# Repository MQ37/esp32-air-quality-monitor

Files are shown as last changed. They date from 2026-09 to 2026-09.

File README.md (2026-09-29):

# ESP32 air-quality monitor




An ESP32 air-quality monitor for my desk: firmware, a 3D-printable enclosure and wiring for BME680, CCS811 and ENS160 sensors.

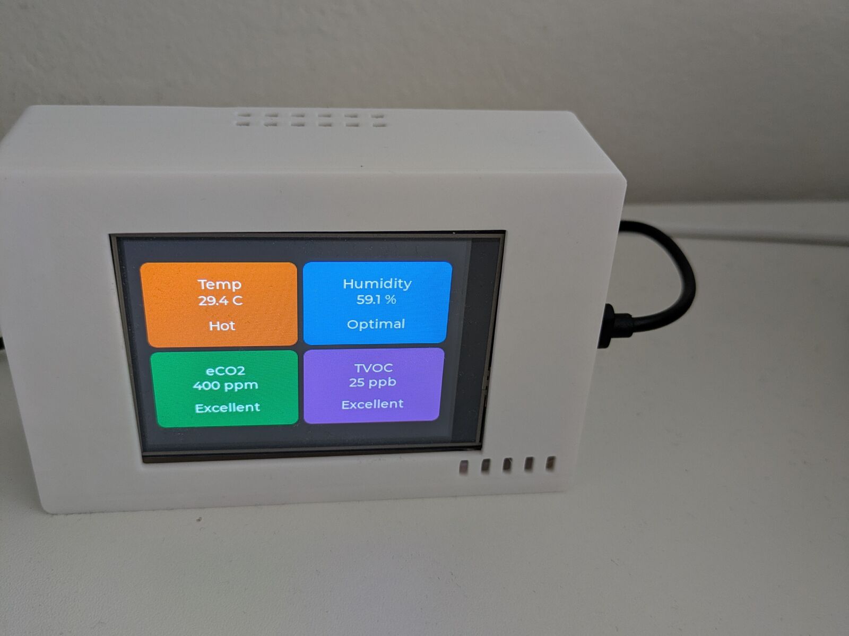
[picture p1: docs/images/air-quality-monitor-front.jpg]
The finished monitor: a white printed case with a screen showing temperature, humidity, eCO2 and TVOC


It shows temperature, humidity, eCO2 and TVOC on the board's built-in 3.2" screen, and this repo has everything I used to build it.

I'm a software person, and the hardware side was the hard part for me. If you're in the same spot, this README spells out the things I had to figure out.

**Blog post:** [ESP32 - building an air-quality monitor with a coding agent](https://kopecky.io/blog/2026-09-28-esp32-air-quality-monitor/)

> **Status: the cleaned-up firmware in this repo is untested on hardware.** I built this monitor and ran an earlier, messier version of the firmware on it. Then I tidied the code for this repo (LVGL from the component manager, shared I2C helper, one pins header, BME680 gas heater off, a fix to the eCO2/TVOC averaging). It compiles cleanly with ESP-IDF v5.5.2, but I'm traveling and can't flash the board right now, so this exact version hasn't run on it yet. If something breaks, please open an issue.

---

- [What it measures](#what-it-measures)
- [Bill of materials](#bill-of-materials)
- [How it's wired](#how-its-wired)
- [The enclosure](#the-enclosure)
- [Build and flash the firmware](#build-and-flash-the-firmware)
- [Troubleshooting](#troubleshooting)
- [How the firmware works](#how-the-firmware-works)
- [Repo layout](#repo-layout)
- [Notes and lessons learned](#notes-and-lessons-learned)
- [Acknowledgements and licenses](#acknowledgements-and-licenses)

## What it measures

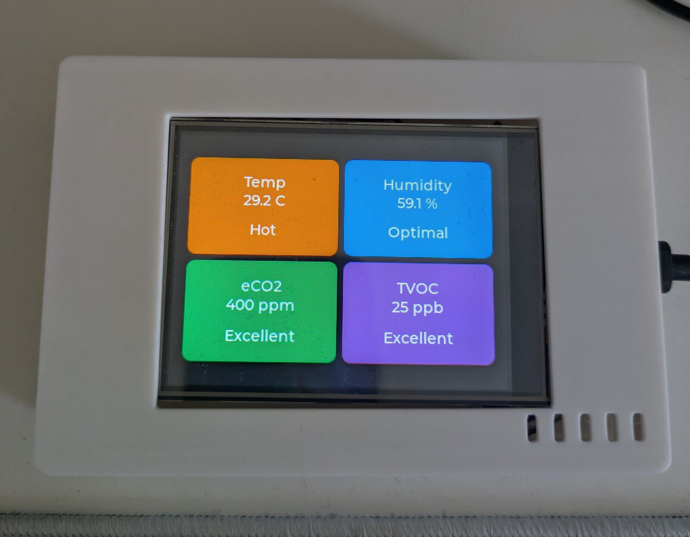
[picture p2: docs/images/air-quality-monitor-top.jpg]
Close-up of the screen with its four cards


| Card | Sensor | Label under the value, from low to high |
| --- | --- | --- |
| **Temp** (°C) | BME680 | Cold (< 18) · Cool (18–20) · Comfortable (20–26) · Warm (26–28) · Hot (≥ 28) |
| **Humidity** (% RH) | BME680 | Dry (< 30) · Low (30–40) · Optimal (40–60) · High (60–70) · Humid (≥ 70) |
| **eCO2** (ppm) | CCS811 | Excellent (< 600) · Good (600–800) · Fair (800–1000) · Poor (1000–1500) · Very Poor (≥ 1500) |
| **TVOC** (ppb) | ENS160 | Excellent (< 100) · Good (100–200) · Fair (200–400) · Poor (400–600) · Very Poor (≥ 600) |

**Four values, three sensor modules.** The BME680 module gives temperature and humidity, the CCS811 module gives eCO2 and the ENS160 module gives TVOC. The ENS160 board is a two-in-one: it also carries an AHT21 temperature and humidity chip, which the firmware doesn't read. The bill of materials below lists exactly what I bought.

The sensors are read every 5 seconds, and each card shows the average of the last 5 readings (about 25 seconds). The label thresholds are rough rules of thumb I picked, not an official standard. They live in [`ui_air_quality.c`](firmware/main/ui_air_quality.c) if you want different ones.

Before you trust the numbers:

- **Warm-up.** The gas sensors need time after power-on. Until the CCS811 delivers its first reading, the eCO2 card shows **"Warming" / "Please wait"**. The ENS160 reports TVOC while it is still warming up, and the firmware shows those values, so treat the first readings as rough. The log reminds you that the CCS811 needs about 20 minutes and the ENS160 about an hour for full accuracy.
- **eCO2 is an estimate.** The CCS811 doesn't measure CO2. It estimates an "equivalent CO2" from the gases it detects, and its lowest output is 400 ppm. So "400 ppm" means "clean air", not an exact measurement.
- **Temperature reads high.** The ESP32 and the display backlight heat up the inside of the box, and the case has almost no airflow, so the temperature card shows noticeably more than the real room temperature (my photos show about 29 °C). The BME680's gas heater is switched off in the firmware so it doesn't add to this (see [`bme680_driver.c`](firmware/main/bme680_driver.c)). Treat the temperature as approximate. A better enclosure would fix most of it, see [the enclosure section](#the-enclosure).
- **Compensation.** Every reading, the BME680's temperature and humidity are passed to the CCS811 and ENS160 so they can correct their gas readings.

**Why so many sensors?** Several of them overlap: the CCS811 and the ENS160 both report eCO2 and TVOC, and both the BME680 and the AHT21 measure temperature and humidity. I read that when a gas sensor is also used for temperature, its other readings get worse. So instead of working around that, I bought more sensors and gave each one a single job: the firmware takes temperature and humidity from the BME680, eCO2 from the CCS811 and TVOC from the ENS160.

## Bill of materials

| Part | Qty | Notes |
| --- | --- | --- |
| ESP32-32E 3.2" display board ("E32R32P") | 1 | ESP32-WROOM-32, 240x320 ST7789P3 IPS display, XPT2046 resistive touch. [The AliExpress listing I bought from](https://www.aliexpress.com/item/1005008239809369.html). |
| BME680 module (sold as "CJMCU-680") | 1 | Bosch temperature / humidity / pressure / gas sensor. Used for temperature and humidity. I2C address 0x77. |
| CCS811 air-quality module | 1 | eCO2 / TVOC sensor. Used for eCO2. I2C address 0x5A. |
| ENS160 + AHT21 module | 1 | One board with two chips: the ScioSense ENS160 air-quality sensor (used for TVOC, I2C address 0x53) and an AHT21 temperature and humidity sensor (not used by the firmware, usually at address 0x38). |
| M2.5 self-tapping screws | 4 | Hold the board on the enclosure standoffs. |
| USB-C cable + 5 V USB power supply | 1 | For power, and for flashing from your computer. |
| Wire | – | Four wires per sensor, plus one for the CCS811's nWAKE pin. I soldered mine. |
| PLA filament | ~67 g | For the [enclosure](enclosure/). |

That is three sensor modules and four sensor chips. Sensor breakouts come from many sellers and differ in pin names and address jumpers, so check the notes below against your modules.

## How it's wired

The display and touch screen are built into the board. The only wiring is the three sensor modules, which all share **one I2C bus**:

Wiring diagram: ESP32-32E to BME680, CCS811 and ENS160 on one I2C bus

| ESP32-32E | BME680 | CCS811 | ENS160 (+ AHT21) |
| --- | --- | --- | --- |
| 3V3 | VCC | VCC | VCC |
| GND | GND | GND **and nWAKE** | GND |
| GPIO32 (SDA) | SDA | SDA | SDA |
| GPIO25 (SCL) | SCL | SCL | SCL |

- **I2C** is a two-wire bus (SDA = data, SCL = clock) that several chips can share. Each chip has its own address, so they don't clash.
- **CCS811 nWAKE → GND.** The CCS811 only answers on I2C while nWAKE is low, so tie it to ground.
- **Addresses.** The firmware expects BME680 `0x77`, CCS811 `0x5A` and ENS160 `0x53`. On boot it scans the bus and logs every address it finds, which is the quickest way to check your wiring. The scan will also list the AHT21 on the ENS160 board (usually `0x38`); the firmware ignores it. If a module shows up at its other address (BME680 `0x76`, CCS811 `0x5B`, ENS160 `0x52`), change the address constant at the top of its driver in [`firmware/main/`](firmware/main/), or change the address pin on the module.
- **Pull-ups.** I2C needs pull-up resistors on SDA and SCL. The firmware turns on the ESP32's internal ones, and most breakout modules have their own.
- **Check your module.** Pin labels vary (VCC/VIN/3V3, ADD/ADDR/SDO), and so does whether a module runs on 3.3 V. Where 3V3, GND, GPIO32 and GPIO25 come out on the board depends on its connectors, so check the seller's pinout.

### Full pin map

All GPIOs are defined in [`firmware/main/pins.h`](firmware/main/pins.h). The display driver reads its pins from [`firmware/sdkconfig.defaults`](firmware/sdkconfig.defaults), and the build fails if the two files ever disagree.

| Function | GPIO | Notes |
| --- | --- | --- |
| I2C SDA (sensors) | 32 | 100 kHz |
| I2C SCL (sensors) | 25 | |
| SPI MOSI (display + touch) | 13 | SPI2 / HSPI |
| SPI MISO (touch) | 12 | |
| SPI CLK (display + touch) | 14 | |
| Display CS | 15 | |
| Display DC | 2 | |
| Display backlight | 27 | active high |
| Display reset | – | tied to the ESP32 EN pin; the driver sends a software reset instead |
| Touch CS | 33 | |
| Touch IRQ | 36 | input-only pin |

## The enclosure

| Assembled | Exploded |
| --- | --- |
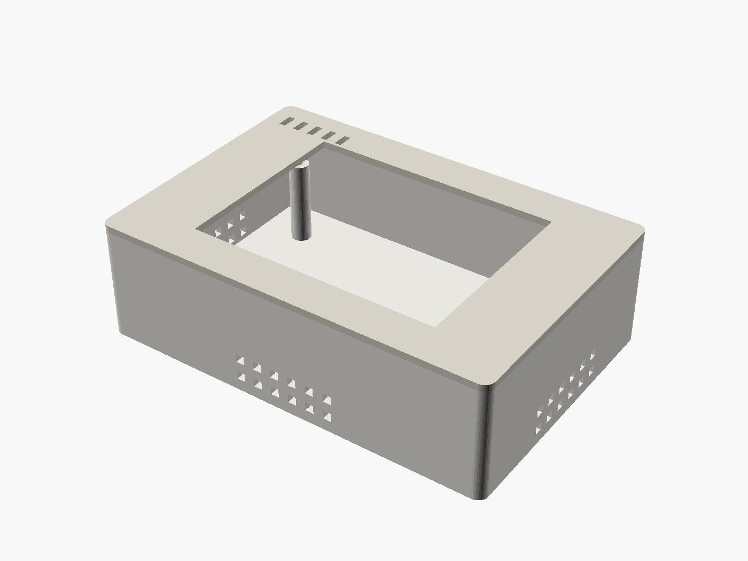
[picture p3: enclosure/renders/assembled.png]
Assembled enclosure render
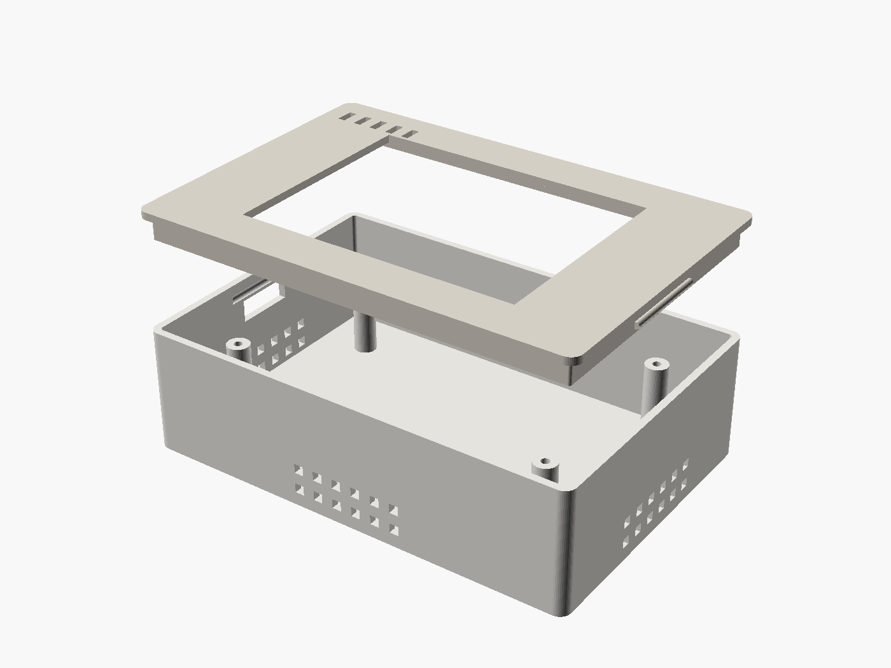
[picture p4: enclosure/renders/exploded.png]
Exploded enclosure render
|  |  |

Two printed parts, designed in OpenSCAD:

- **Base:** four standoffs for the board (M2.5 self-tapping screws), a USB-C opening, vent holes low on three walls, and 25 mm of room under the board for the sensors.
- **Lid:** a window for the display and five exhaust slots. It snaps into the base with a bead on each side, so it needs no screws.

**Known limitation: airflow.** The vents turned out to be too few and too small. The ESP32 and the backlight keep heating the closed box, air barely moves through it, and the temperature reading ends up well above the room temperature. The next iteration should have more ventilation, so that air really flows past the sensors, or the sensors should sit outside the warm part of the case. Pull requests to the SCAD files are welcome.

The outer size is 118 x 80 x 35 mm. I printed both parts in PLA on a Prusa CORE One (0.4 mm nozzle, 0.2 mm layers) in about 1.5 hours. The STLs are in [`enclosure/stl/`](enclosure/stl/). Dimensions, print settings and how to adapt the case to a different board are in [`enclosure/README.md`](enclosure/README.md).

## Build and flash the firmware

The firmware is an [ESP-IDF](https://docs.espressif.com/projects/esp-idf/en/v5.5.2/esp32/) project in [`firmware/`](firmware/), with a [LVGL](https://lvgl.io/) 8.3 UI. It's tested with **ESP-IDF v5.5.2**. LVGL is downloaded automatically on the first build.

### Option A: build in a container (only needs Docker or Podman)

```sh
git clone https://github.com/MQ37/esp32-air-quality-monitor.git
cd esp32-air-quality-monitor/firmware

podman run --rm -v "$PWD":/project:Z -w /project docker.io/espressif/idf:v5.5.2 \
  bash -c 'idf.py set-target esp32 && idf.py build'
```

With Docker, replace `podman` with `docker` (the `:Z` suffix only matters on SELinux systems). The build leaves `build/esp32-air-quality-monitor.bin`, the bootloader and the partition table in `build/`.

To flash from your computer, install [esptool](https://docs.espressif.com/projects/esptool/) (`pip install esptool`) and run this from the `build/` folder. It's the command the build prints, plus the serial port:

```sh
cd build
python -m esptool --chip esp32 -p /dev/ttyUSB0 -b 460800 \
  --before default_reset --after hard_reset write_flash "@flash_args"
```

Then open any serial monitor at **115200 baud** to see the log.

### Option B: native ESP-IDF

Install ESP-IDF v5.5.2 following [Espressif's guide](https://docs.espressif.com/projects/esp-idf/en/v5.5.2/esp32/get-started/index.html), then:

```sh
cd esp32-air-quality-monitor/firmware
. $HOME/esp/esp-idf/export.sh        # wherever you installed ESP-IDF
idf.py set-target esp32
idf.py build
idf.py -p /dev/ttyUSB0 flash monitor # Ctrl+] quits the monitor
```

### Finding your serial port

Plug the board in over USB-C and look for the new device:

- **Linux:** `ls /dev/ttyUSB* /dev/ttyACM*` (or `dmesg | tail` right after plugging in). If you get "permission denied", add yourself to the `dialout` group (`uucp` on Arch) and log in again.
- **macOS:** `ls /dev/cu.*`
- **Windows:** Device Manager → *Ports (COM & LPT)*, then use e.g. `-p COM5`.

If no port shows up, try another cable (some are charge-only) or install the driver for your board's USB-serial chip.

### Changing settings

Build settings live in [`firmware/sdkconfig.defaults`](firmware/sdkconfig.defaults). ESP-IDF creates `firmware/sdkconfig` from it on the first build and uses that file from then on, so after editing the defaults, delete `firmware/sdkconfig` and rebuild. For quick experiments, `idf.py menuconfig` edits `sdkconfig` directly.

## Troubleshooting

Most of these cost me time. The display ones are already fixed in this repo; they're here so you recognise them if you change the display settings or port this to another board (background in [docs/display-init.md](docs/display-init.md)).

| Symptom | Likely cause | What to do |
| --- | --- | --- |
| Backlight is on but the screen stays black | Wrong SPI mode | The ST7789P3 needs SPI **mode 0** (`SPI_TFT_SPI_MODE` in `lvgl_spi_conf.h`). Mode 2, the upstream default, gives exactly this. |
| Colours look inverted, like a negative | Display inversion off | Keep `CONFIG_LV_INVERT_COLORS=y` (IPS panel). |
| Colours are wrong but not inverted | RGB565 byte order | Keep `CONFIG_LV_COLOR_16_SWAP=y`. |
| Garbled or unstable picture | SPI clock too fast | The driver uses 5 MHz. If you raised it, go back down. |
| Display never initialises (e.g. on a similar board) | Panel reset isn't on a GPIO | On this board the panel reset is tied to EN, so keep `CONFIG_LV_DISP_USE_RST=n`. The driver then sends a software reset. |
| Log says `No I2C devices found` | Sensor wiring | Check 3V3 and GND, and that SDA and SCL aren't swapped. |
| `CCS811 initialization failed` / `Failed to read HW ID` | nWAKE floating or wrong address | Tie CCS811 nWAKE to GND. Check the scan log for 0x5A vs 0x5B. |
| `BME680 init failed` | Module at 0x76 | Use `BME68X_I2C_ADDR_LOW` in `bme680_driver.c`, or pull SDO high. |
| eCO2 or TVOC stays on "Warming" | Normal after power-on | The gas sensors need time. The log shows what they report while warming up. |
| eCO2 always shows 400 ppm | Clean air | 400 ppm is the CCS811's lowest output. |
| Touch is offset or mirrored (if you add a touch UI) | Calibration | Adjust `CONFIG_LV_TOUCH_*` in `sdkconfig.defaults`. |
| Changes in `sdkconfig.defaults` seem ignored | Old `sdkconfig` | Delete `firmware/sdkconfig` and rebuild. |

## How the firmware works

Everything runs in one loop in `app_main`, with no tasks of its own:

1. **Start-up** ([`main.c`](firmware/main/main.c)): switch on the backlight, init NVS, start the I2C bus and scan it, and init the three sensor modules. Then init LVGL and the display ([`lvgl_port.c`](firmware/main/lvgl_port.c)) and draw the four cards ([`ui_air_quality.c`](firmware/main/ui_air_quality.c)).
2. **Every 10 ms:** `lv_timer_handler()` lets LVGL redraw. A 10 ms `esp_timer` drives LVGL's clock.
3. **Every 5 s:** trigger a BME680 measurement and read temperature and humidity, pass both to the CCS811 and ENS160 for compensation, then read TVOC from the ENS160 and eCO2 from the CCS811. Each value goes into a 5-slot ring buffer, and the cards show the averages. A gas value of 0 means "no data yet": it's left out of the average, and the card shows "Warming" until a real reading arrives.

The drivers are small:

- [`bme680_driver.c`](firmware/main/bme680_driver.c) wraps Bosch's BME68x Sensor API (forced mode).
- [`ccs811_driver.c`](firmware/main/ccs811_driver.c) is a minimal register-level driver (1-second measurement mode).
- [`ens160_driver.c`](firmware/main/ens160_driver.c) wraps ScioSense's official C driver (standard mode).
- [`i2c_bus.c`](firmware/main/i2c_bus.c) has the register read/write helpers all three share.

The display side uses a patched copy of [lvgl_esp32_drivers](https://github.com/lvgl/lvgl_esp32_drivers) (ST7789 + XPT2046 over SPI). Touch is registered with LVGL, but the current UI doesn't use it.

## Repo layout

```text
.
├── firmware/                      ESP-IDF project (run idf.py here)
│   ├── main/                      application code
│   │   ├── main.c                 start-up + main loop
│   │   ├── pins.h                 every GPIO in one place
│   │   ├── i2c_bus.c/.h           shared I2C helpers
│   │   ├── bme680_driver.c/.h     BME680 wrapper
│   │   ├── ccs811_driver.c/.h     CCS811 driver
│   │   ├── ens160_driver.c/.h     ENS160 wrapper
│   │   ├── lvgl_port.c/.h         LVGL <-> display/touch glue
│   │   ├── ui_air_quality.c/.h    the four-card screen
│   │   └── idf_component.yml      pulls LVGL 8.3.11 from the component registry
│   ├── components/
│   │   ├── lvgl_esp32_drivers/    display + touch drivers (patched, see THIRD_PARTY.md)
│   │   ├── bme68x/                Bosch BME68x Sensor API v4.4.8
│   │   └── sciosense_ens160/      ScioSense ENS160 driver
│   ├── sdkconfig.defaults         build settings (display, touch, pins)
│   ├── partitions.csv             4 MB flash layout with a 3 MB app slot
│   └── dependencies.lock          exact component versions
├── enclosure/                     OpenSCAD sources, STLs, renders (CC BY 4.0)
├── docs/
│   ├── wiring.svg                 wiring diagram
│   ├── display-init.md            ST7789P3 bring-up notes and init sequence
│   ├── images/                    photos
│   └── social-preview.png         the repo's social card image
├── LICENSE                        MIT (firmware and docs)
└── THIRD_PARTY.md                 third-party code, versions and patches
```

## Notes and lessons learned

- **The hardware was the hard part.** The board came with a couple of example files and a thin datasheet. Getting from "the demo works" to my own firmware meant fighting build errors, flashing and pin configuration. For a while the backlight was on but the screen stayed black, which turned out to be the wrong SPI mode.
- **A coding agent got me through it.** I'm not experienced with embedded tooling. Working through the build errors, flashing and pin config together with a coding agent is what made this project happen.
- **An LLM designed the enclosure.** I measured the board and its holes and gave the numbers to an LLM (I think GLM 5.1 or one of the Kimi models, I don't remember exactly), which wrote the OpenSCAD code for a two-part case. I printed it, screwed the board in and that was it.
- **First time soldering.** The joints aren't pretty, but they work.
- **The case runs hot.** The enclosure traps heat, so the temperature reads much higher than it really is. The next version needs more ventilation.

## Acknowledgements and licenses

- My code and docs: [MIT](LICENSE). Enclosure files: [CC BY 4.0](enclosure/LICENSE).
- [LVGL](https://lvgl.io/) (MIT) for the UI.
- [lvgl_esp32_drivers](https://github.com/lvgl/lvgl_esp32_drivers) (MIT) for the display and touch drivers, patched here for ESP-IDF 5 and this panel.
- [Bosch Sensortec BME68x Sensor API](https://github.com/boschsensortec/BME68x_SensorAPI) (BSD-3-Clause).
- [ScioSense ENS16x driver](https://github.com/sciosense/ens16x-arduino) (MIT).
- [Espressif ESP-IDF](https://github.com/espressif/esp-idf) (Apache-2.0).

Versions, upstream links and the exact list of local changes are in [THIRD_PARTY.md](THIRD_PARTY.md).

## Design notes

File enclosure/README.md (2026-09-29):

# Enclosure

A two-part, 3D-printable case for the ESP32-32E board and its sensors, written in [OpenSCAD](https://openscad.org/).

Exploded view of the enclosure

| Base | Lid (flipped, showing the skirt) |
| --- | --- |
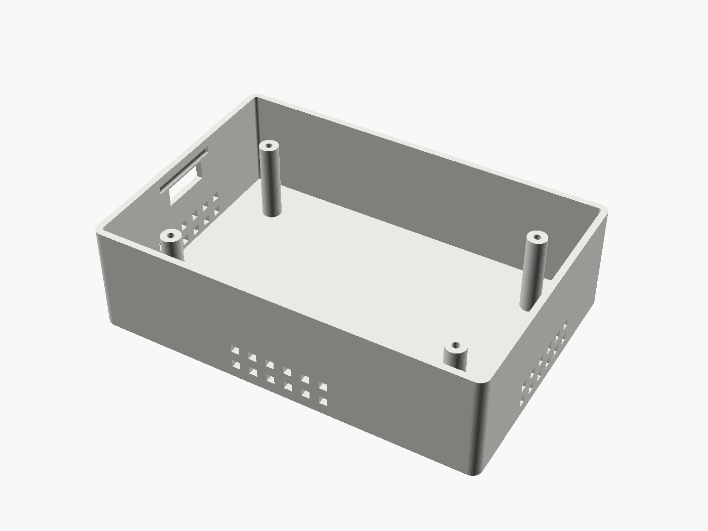
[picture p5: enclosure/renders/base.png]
Base
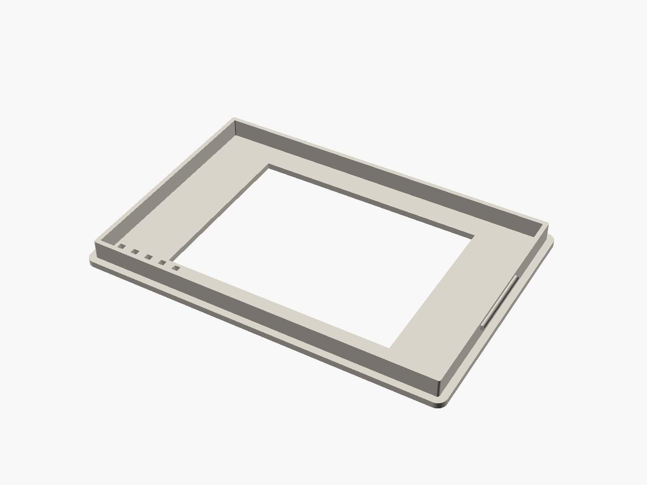
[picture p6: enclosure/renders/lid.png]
Lid
|  |  |

- **Base**: an open box with four standoffs for the board, a USB-C opening in the left wall, two rows of vent holes low on three walls, and 25 mm of free space under the board for the sensor modules.
- **Lid**: a frame with a window for the display and five exhaust slots. A skirt drops into the base, and a small bead on each side clicks into a groove in the base wall. No screws. Press to close, pry to open.

The idea is that air comes in through the low wall vents, passes the sensors and leaves through the lid slots. In practice the airflow is weak, the box heats up and the temperature reading comes out high, so a next version should have more ventilation.

## Files

| File | What it is |
| --- | --- |
| `common.scad` | All dimensions and shared helpers. Start here if you want to change something. |
| `case_base.scad` | The base. |
| `case_top.scad` | The lid. |
| `assembly.scad` | Preview only: assembled / exploded / single-part views used for the renders. |
| `stl/case_base.stl`, `stl/case_top.stl` | Ready-to-slice exports of the two parts. |
| `renders/*.png` | Preview images. |

The STLs match the current `.scad` files.

## Dimensions

| Part | Size |
| --- | --- |
| Outer size (closed) | 118 x 80 x 35 mm |
| Board | 94 x 56 mm, 5.5 mm total stack height (PCB + display + parts on the back) |
| Board holes | one per corner, centres 3 mm in from each edge, so 88 x 50 mm apart |
| Standoffs | 6 mm diameter, 25 mm tall, 2.2 mm pilot hole for **M2.5 self-tapping screws** (4 needed) |
| Space under the board | 25 mm |
| Display window | 74 x 56 mm (the board is 94 mm wide; 10 mm on each side is not display) |
| USB-C opening | 16 x 6 mm, centred on the left wall |
| Walls / floor / lid plate | 2 mm |
| Clearance around the board | 10 mm on every side, for cables |

If your board differs, measure it and change `board_w`, `board_l`, `board_th`, `hole_inset` and `disp_w` / `disp_l` in `common.scad`. Everything else is derived from those.

## Printing

What I used: **Prusa CORE One, PLA, 0.4 mm nozzle, 0.2 mm layers** (OrcaSlicer, "0.20mm SPEED @CORE One HF 0.4" profile, 15 % infill, 2 walls). Both parts on one plate took about 1 h 33 min and 67 g of filament.

Orientation: the base prints open side up, as exported. The lid STL is exported the way it sits on the case (skirt down), so flip it in the slicer and print it with its flat top on the bed.

Supports: I had the slicer's automatic supports switched on. They only ended up in the base, inside the USB-C opening and the wall vent holes (small horizontal openings in a vertical wall). The lid, printed flat side down, needs none.

The snap fit depends on your printer's tolerances. If the lid is too tight or too loose, tweak `skirt_gap` (clearance) or `snap_r` (bead size) in `common.scad`.

## Exporting and rendering

```sh
openscad -o stl/case_base.stl case_base.scad
openscad -o stl/case_top.stl  case_top.scad

# preview images
openscad --imgsize=1400,1050 --viewall --autocenter --colorscheme=Tomorrow \
  --camera=0,0,0,60,0,35,300 -D 'view="exploded"' -o renders/exploded.png assembly.scad
```

For the other images, set `view` to `"assembled"`, `"base"` or `"lid"` (the lid image uses a different camera angle). The renders here were made with OpenSCAD 2021.01.

## How it was designed

I measured the board and its mounting holes, gave the numbers to an LLM and it wrote the OpenSCAD code. I printed it, screwed the board in and that was it.

## License

The enclosure files are licensed under [CC BY 4.0](LICENSE). The firmware in this repository is MIT-licensed.

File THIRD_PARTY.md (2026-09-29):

# Third-party code and licenses

The code written for this project is MIT-licensed (see [LICENSE](LICENSE)); the enclosure design files are CC BY 4.0 (see [enclosure/LICENSE](enclosure/LICENSE)). The firmware also uses the following third-party code.

| Component | Where | Version | License | Modified? |
| --- | --- | --- | --- | --- |
| [LVGL](https://github.com/lvgl/lvgl) | downloaded at build time by the ESP-IDF Component Manager ([`lvgl/lvgl`](https://components.espressif.com/components/lvgl/lvgl)), pinned in `firmware/dependencies.lock` | 8.3.11 | MIT | No |
| [lvgl_esp32_drivers](https://github.com/lvgl/lvgl_esp32_drivers) | `firmware/components/lvgl_esp32_drivers/` | `master` at commit `26fe6e7` (upstream is archived) | MIT ([LICENSE](firmware/components/lvgl_esp32_drivers/LICENSE)) | **Yes**, see below |
| [Bosch BME68x Sensor API](https://github.com/boschsensortec/BME68x_SensorAPI) | `firmware/components/bme68x/` | v4.4.8 | BSD-3-Clause ([LICENSE](firmware/components/bme68x/LICENSE)) | No (files are byte-identical to the v4.4.8 tag) |
| [ScioSense ENS16x Arduino library](https://github.com/sciosense/ens16x-arduino), the plain-C part in `src/lib/ens16x/` | `firmware/components/sciosense_ens160/` | 2.0.5 | MIT ([LICENSE](firmware/components/sciosense_ens160/LICENSE)) | No (byte-identical `ScioSense_Ens160*.h`) |
| [ESP-IDF](https://github.com/espressif/esp-idf) | not included; you install it or use the Docker image | 5.5.2 | Apache-2.0 | – |

Only the Bosch **BME68x Sensor API** (BSD-3-Clause) is used for the BME680. Bosch's separate, proprietary **BSEC** library is *not* used or included.

The `CMakeLists.txt` files in `components/bme68x/` and `components/sciosense_ens160/` were added by this project to make them ESP-IDF components.

## Changes to lvgl_esp32_drivers

The upstream component predates ESP-IDF 5 and has been archived in favour of [lvgl/lv_esp_idf](https://github.com/lvgl/lv_esp_idf). The copy here is based on upstream `master` (commit `26fe6e7`, "clarify the 52/53 px offset oddity") with these changes:

**Removed (not needed to build):** `.github/`, `.editorconfig`, `.gitignore`, `component.mk` (legacy GNU Make build), `README.md`, `lvgl_i2c/README.md`, `CONTRIBUTE_CONTROLLER_SUPPORT.md`. All driver sources were kept, so the Kconfig menus still work for other panels.

**ESP-IDF 5.x compatibility:**
- `gpio_pad_select_gpio()` → `esp_rom_gpio_pad_select_gpio()` in `lvgl_tft/st7789.c`, `lvgl_tft/ili9341.c`, `lvgl_tft/st7796s.c` and `lvgl_tft/esp_lcd_backlight.c`.
- `portTICK_RATE_MS` → `portTICK_PERIOD_MS` in `lvgl_tft/st7789.c`, `lvgl_tft/ili9341.c` and `lvgl_tft/st7796s.c`.
- `lvgl_tft/esp_lcd_backlight.c`: LEDC `bit_num` → `duty_resolution`; include `rom/gpio.h` (instead of `driver/gpio.h`) and `soc/gpio_sig_map.h`.
- `lvgl_helpers.c` (`lvgl_spi_driver_init`): per-target SPI host checks/names and `SPI_DMA_CH_AUTO`.
- `CMakeLists.txt`: add `driver` to `REQUIRES`.
- `lvgl_helpers.h`: define `LV_HOR_RES_MAX` / `LV_VER_RES_MAX` (320 x 240), which LVGL 8 no longer provides.
- `lvgl_tft/disp_spi.c`: drop the duplicate `IRAM_ATTR` on the `spi_ready` forward declaration (silences a GCC warning; the definition keeps it).

**Changes for the ESP32-32E / ST7789P3 panel** (details in [docs/display-init.md](docs/display-init.md)):
- `lvgl_spi_conf.h`: ST7789 SPI mode 2 → **0**, SPI clock 20 MHz → **5 MHz**.
- `lvgl_tft/st7789.c`: init table replaced with the panel vendor's register values (written as a commented table, no vendor code copied); software reset now waits 150 ms; MADCTL values for the two portrait orientations swapped; log via `ESP_LOGI` instead of `printf`.

## LVGL port

`firmware/main/lvgl_port.c` started from LVGL's porting templates (`lv_port_disp_templ.c` / `lv_port_indev_templ.c`, MIT) and was reduced to the few lines this board needs.

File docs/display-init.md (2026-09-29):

# Display bring-up notes (ST7789P3)

The ESP32-32E ("E32R32P") has a 3.2" 240x320 IPS panel driven by an ST7789P3 controller over SPI. The generic ST7789 driver in `lvgl_esp32_drivers` did not work on it out of the box. This page lists what had to change and why. The code is in [`firmware/components/lvgl_esp32_drivers/lvgl_tft/st7789.c`](../firmware/components/lvgl_esp32_drivers/lvgl_tft/st7789.c) and [`lvgl_spi_conf.h`](../firmware/components/lvgl_esp32_drivers/lvgl_spi_conf.h).

## The quirks

| Symptom | Cause | Fix in this repo |
| --- | --- | --- |
| Backlight on, screen stays black | Upstream uses SPI mode 2 for ST7789; this panel needs **mode 0** | `SPI_TFT_SPI_MODE (0)` in `lvgl_spi_conf.h` |
| Colours look like a photo negative | IPS panels need display inversion | `CONFIG_LV_INVERT_COLORS=y` → the driver sends `INVON` (0x21) |
| No reset GPIO to toggle | The panel's reset line is wired to the ESP32 **EN** pin | `CONFIG_LV_DISP_USE_RST=n`; the driver sends a software reset (0x01) and waits 150 ms |
| Unreliable picture during bring-up | SPI clock too fast | SPI clock lowered to **5 MHz** (upstream: 20 MHz). Faster may work; I haven't tested it |
| Upstream init table is for other ST7789 panels | Voltages, gamma and timing differ per panel | Replaced with the panel vendor's register values (below). VCOMS is the vendor's 0x13; an earlier 0x23 was less stable |

Also needed: `CONFIG_LV_COLOR_16_SWAP=y` (LVGL's RGB565 bytes must be swapped for SPI), and 320x240 landscape (`CONFIG_LV_DISPLAY_ORIENTATION_LANDSCAPE=y`, `LV_HOR_RES_MAX`/`LV_VER_RES_MAX` in `lvgl_helpers.h`).

## Init sequence

Sent once at start-up, after the software reset. Values come from the panel vendor's example code; the descriptions are mine, based on the ST7789 command set.

| Cmd | Name | Data | What it does |
| --- | --- | --- | --- |
| `0x36` | MADCTL | `00` | Memory access order. Overwritten right after the table by the orientation setting (`0x60` for landscape). |
| `0x3A` | COLMOD | `05` | 16 bits per pixel (RGB565). |
| `0xB2` | PORCTRL | `0C 0C 00 33 33` | Porch (blanking) timing. |
| `0xB7` | GCTRL | `74` | Gate driver voltages (VGH / VGL). |
| `0xBB` | VCOMS | `13` | VCOM voltage. |
| `0xC0` | LCMCTRL | `2C` | LCM control. |
| `0xC2` | VDVVRHEN | `01` | Take VDV and VRH from the next two commands. |
| `0xC3` | VRHS | `10` | VRH: gamma reference voltage. |
| `0xC4` | VDVSET | `20` | VDV: voltage offset. |
| `0xC6` | FRCTRL2 | `0F` | Frame rate in normal mode (0x0F is 60 Hz). |
| `0xD0` | PWCTRL1 | `A4 A1` | Power control 1 (AVDD / AVCL / VDS). |
| `0xD6` | – | `A1` | Vendor-specific; kept as the vendor had it. |
| `0xE0` | PVGAMCTRL | `D0 07 0E 0B 0A 14 38 33 4F 37 16 16 2A 2E` | Positive gamma curve. |
| `0xE1` | NVGAMCTRL | `D0 0B 10 08 08 06 35 54 4D 0A 14 14 2C 2F` | Negative gamma curve. |
| `0xE9` | EQCTRL | `11 11 03` | Equalize time control. |
| `0x21` | INVON | – | Display inversion on (IPS). |
| `0x11` | SLPOUT | – | Leave sleep mode, then wait 100 ms. |
| `0x29` | DISPON | – | Display on, then wait 100 ms. |

After that, every LVGL flush sets the window with `CASET` (0x2A) / `RASET` (0x2B) and streams pixels with `RAMWR` (0x2C).

## Orientation

`st7789_set_orientation()` picks a MADCTL value per orientation. This board uses **landscape (0x60)**. The two portrait entries are swapped compared to upstream (`0x00` / `0xC0` instead of `0xC0` / `0x00`) to suit this panel; landscape is the same as upstream.

## Touch

The XPT2046 touch controller shares the SPI bus (MOSI 13, MISO 12, CLK 14) with its own chip select (GPIO33) and an IRQ line on GPIO36. Calibration values are in `firmware/sdkconfig.defaults` (`CONFIG_LV_TOUCH_X_MIN` ... `CONFIG_LV_TOUCH_INVERT_Y`). The current UI does not use touch, but the input device is registered with LVGL.

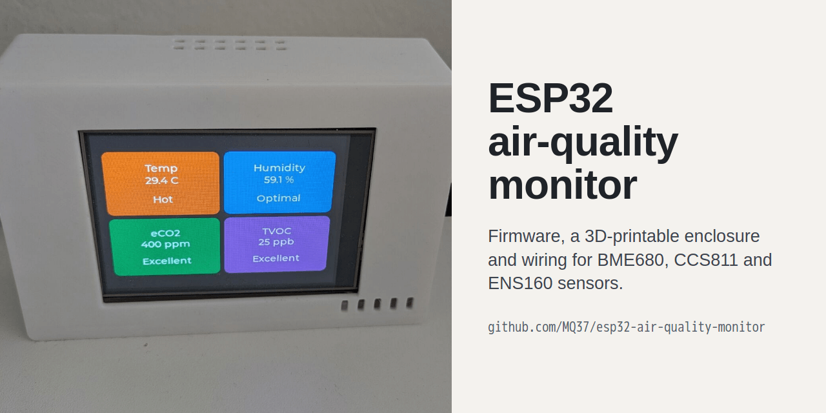
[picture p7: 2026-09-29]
docs/social-preview.png

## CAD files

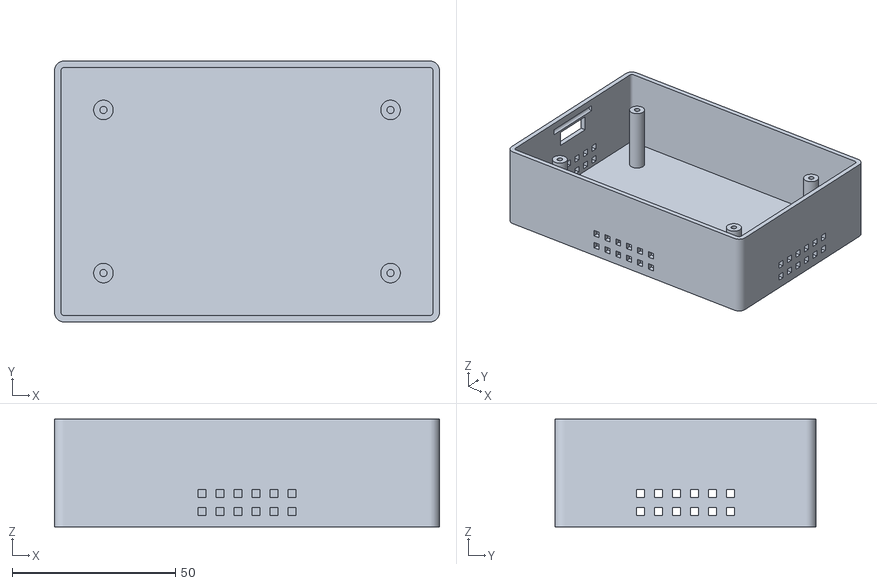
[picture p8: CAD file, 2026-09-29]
enclosure/stl/case_base.stl
118.0 x 80.0 x 33.0

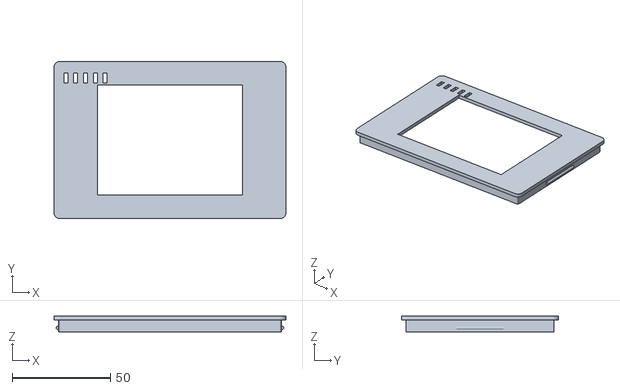
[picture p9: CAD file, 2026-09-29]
enclosure/stl/case_top.stl
118.0 x 80.0 x 8.00

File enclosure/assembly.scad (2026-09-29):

// assembly.scad — preview only (not for printing): base and lid together.
//
//   openscad assembly.scad                          # exploded view
//   openscad -D 'view="assembled"' assembly.scad    # lid snapped on
//   openscad -D 'view="base"' assembly.scad         # base only
//   openscad -D 'view="lid"' assembly.scad          # lid only, flipped to show the skirt and snap beads
//
// Print the parts from case_base.scad / case_top.scad (or the files in stl/).

include <common.scad>
use <case_base.scad>
use <case_top.scad>

view    = "exploded";   // "assembled" | "exploded" | "base" | "lid"
explode = 30;           // lid lift in the exploded view (mm)

if (view == "assembled") {
    color("#e8e6e1") base();
    color("#d6d1c7") lid();
} else if (view == "base") {
    color("#e8e6e1") base();
} else if (view == "lid") {
    // upside down, so the skirt and the snap beads face the camera
    color("#d6d1c7")
        translate([0, outer_l, base_h + lid_t]) rotate([180, 0, 0]) lid();
} else {
    color("#e8e6e1") base();
    color("#d6d1c7") translate([0, 0, explode]) lid();
}

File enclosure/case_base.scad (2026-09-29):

// case_base.scad — ESP32 air-quality monitor enclosure: BASE
//
// Open-top box; the board screws onto four corner standoffs (M2.5 self-tapping
// screws into 2.2 mm pilot holes), with 25 mm of space underneath for sensors.
// USB-C opening centred on the left wall; fresh-air louvers on three walls.
// Snap grooves in the side walls accept the lid's snap beads.
//
// Export:  openscad -o stl/case_base.stl case_base.scad

include <common.scad>

module standoffs() {
    for (x = [board_x0 + hole_inset, board_x0 + board_w - hole_inset],
         y = [board_y0 + hole_inset, board_y0 + board_l - hole_inset])
        translate([x, y, floor_t])
            difference() {
                cylinder(d = standoff_d, h = post_h);
                translate([0, 0, -0.01])
                    cylinder(d = screw_pilot_d, h = post_h + 0.02);
            }
}

module base() {
    difference() {
        rounded_prism(outer_w, outer_l, base_h, corner_r);

        // hollow the cavity (overshoot the top to leave only the floor)
        translate([wall, wall, floor_t])
            rounded_prism(inner_w, inner_l, base_h, inner_r);

        // USB-C power opening in the left wall, centred (generous for slop)
        translate([-0.01, outer_l / 2 - usb_w / 2, usb_zc - usb_h / 2])
            cube([wall + 0.02, usb_w, usb_h]);

        // fresh-air intake louvers
        wall_louvers("front");
        wall_louvers("left");
        wall_louvers("right");

        // snap grooves in the side walls
        for (x = snap_x) snap_bead(x, groove_r);
    }
    standoffs();
}

base();

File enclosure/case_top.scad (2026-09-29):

// case_top.scad — ESP32 air-quality monitor enclosure: LID (top)
//
// Drops in with a skirt; a rounded snap-bead on each side wall
// clicks into a matching groove in the base → press to close, pry to open.
// Display window centred over the board; exhaust slots in the top strip.
//
// Export:  openscad -o stl/case_top.stl case_top.scad
// (exported skirt-down, i.e. in the assembled orientation moved to z = 0;
//  flip it in the slicer and print it flat top on the bed)

include <common.scad>

module lid() {
    translate([0, 0, base_h]) {
        difference() {
            rounded_prism(outer_w, outer_l, lid_t, corner_r);

            // display window, centred over the board
            translate([board_cx - disp_w / 2 + disp_frame,
                       board_cy - disp_l / 2 + disp_frame,
                       -0.01])
                cube([disp_w - 2 * disp_frame, disp_l - 2 * disp_frame, lid_t + 0.02]);

            // exhaust slots in the top strip, left of the connector
            for (i = [0 : vent_rows - 1])
                translate([wall + 3 + i * (vent_slot_w + vent_gap),
                           board_cy + disp_l / 2 + 1,
                           -0.01])
                    cube([vent_slot_w, vent_slot_len, lid_t + 0.02]);
        }
    }

    // skirt ring hanging below the top plate
    translate([wall + skirt_gap, wall + skirt_gap, base_h - skirt_h])
        difference() {
            rounded_prism(inner_w - 2 * skirt_gap, inner_l - 2 * skirt_gap, skirt_h, skirt_r);
            translate([skirt_wall, skirt_wall, -0.01])
                rounded_prism(inner_w - 2 * skirt_gap - 2 * skirt_wall,
                              inner_l - 2 * skirt_gap - 2 * skirt_wall,
                              skirt_h + 0.02,
                              max(skirt_r - skirt_wall, 0.3));
        }

    // snap beads on the skirt
    for (x = snap_x) snap_bead(x, snap_r);
}

// Shift the lid down to the floor so it is not floating in the air.
// The bottom of the skirt (originally at z = base_h - skirt_h) lands at z = 0.
translate([0, 0, -(base_h - skirt_h)])
    lid();

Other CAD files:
enclosure/common.scad

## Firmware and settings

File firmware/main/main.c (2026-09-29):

/*
 * ESP32 air-quality monitor
 *
 * Reads three I2C sensors every 5 seconds and shows a moving average of the
 * last 5 readings on the display:
 *   - BME680: temperature + humidity (also used to compensate the gas sensors)
 *   - CCS811: eCO2
 *   - ENS160: TVOC
 */
#include <stdbool.h>
#include <stdint.h>

#include "driver/gpio.h"
#include "esp_log.h"
#include "freertos/FreeRTOS.h"
#include "freertos/task.h"
#include "lvgl.h"
#include "nvs_flash.h"

#include "bme680_driver.h"
#include "ccs811_driver.h"
#include "ens160_driver.h"
#include "i2c_bus.h"
#include "lvgl_port.h"
#include "pins.h"
#include "ui_air_quality.h"

#define LOOP_PERIOD_MS     10
#define SENSOR_PERIOD_MS   5000
#define AVG_SAMPLES        5      /* 5 samples x 5 s = 25 s moving average */

static const char *TAG = "MAIN";

static void init_nvs(void)
{
    esp_err_t ret = nvs_flash_init();
    if (ret == ESP_ERR_NVS_NO_FREE_PAGES || ret == ESP_ERR_NVS_NEW_VERSION_FOUND) {
        ESP_ERROR_CHECK(nvs_flash_erase());
        ret = nvs_flash_init();
    }
    ESP_ERROR_CHECK(ret);
}

static void init_sensors(void)
{
    i2c_bus_init();
    i2c_bus_scan();

    if (bme680_init_sensor() != 0) {
        ESP_LOGE(TAG, "BME680 initialization failed!");
    } else {
        ESP_LOGI(TAG, "BME680 ready");
    }

    if (ens160_init_sensor() != 0) {
        ESP_LOGE(TAG, "ENS160 initialization failed!");
    } else {
        ESP_LOGI(TAG, "ENS160 ready");
    }

    if (ccs811_init_sensor() != 0) {
        ESP_LOGE(TAG, "CCS811 initialization failed!");
    } else {
        ESP_LOGI(TAG, "CCS811 ready");
    }
}

void app_main(void)
{
    // Switch the backlight on right away so the panel is visibly alive while
    // the sensors initialize (the display driver also drives this pin later).
    gpio_reset_pin(PIN_LCD_BACKLIGHT);
    gpio_set_direction(PIN_LCD_BACKLIGHT, GPIO_MODE_OUTPUT);
    gpio_set_level(PIN_LCD_BACKLIGHT, 1);

    init_nvs();
    init_sensors();

    lvgl_port_init();
    ui_air_quality_init();
    ESP_LOGI(TAG, "UI created, entering main loop");

    bme680_data_t bme_data = {0};
    ens160_data_t ens_data = {0};
    ccs811_data_t ccs_data = {0};
    uint32_t loop_count = 0;

    // Moving-average ring buffers
    float temp_history[AVG_SAMPLES] = {0};
    float humi_history[AVG_SAMPLES] = {0};
    uint16_t eco2_history[AVG_SAMPLES] = {0};
    uint16_t tvoc_history[AVG_SAMPLES] = {0};
    uint8_t history_index = 0;
    uint8_t history_count = 0;

    while (1) {
        lv_timer_handler();

        if (loop_count % (SENSOR_PERIOD_MS / LOOP_PERIOD_MS) == 0) {
            bool bme_ok = false;
            bool ens_ok = false;
            bool ccs_ok = false;

            // BME680: temperature & humidity, then pass them on as
            // compensation data to both gas sensors
            if (bme680_trigger_measurement() == 0) {
                if (bme680_read_data(&bme_data) == 0 && bme_data.valid) {
                    bme_ok = true;
                    ens160_set_compensation(bme_data.temperature, bme_data.humidity);
                    ccs811_set_environment(bme_data.temperature, bme_data.humidity);
                }
            }

            // ENS160 -> TVOC. Returns 0 = ok, 1 = warming up, -1 = error.
            int8_t ens_result = ens160_read_data(&ens_data);
            if (ens_result >= 0 && ens_data.valid) {
                ens_ok = true;
            }
            // During warm-up the values are readable but not yet reliable;
            // they are still shown if they look plausible.
            bool ens_warmup = (ens_result == 1);

            // CCS811 -> eCO2
            int8_t ccs_result = ccs811_read_data(&ccs_data);
            if (ccs_result == 0 && ccs_data.valid) {
                ccs_ok = true;
            }

            ESP_LOGD(TAG, "ENS160: result=%d valid=%d eCO2=%u TVOC=%u AQI=%u | CCS811: result=%d valid=%d eCO2=%u TVOC=%u",
                     ens_result, ens_data.valid, ens_data.eco2, ens_data.tvoc, ens_data.aqi,
                     ccs_result, ccs_data.valid, ccs_data.eco2, ccs_data.tvoc);

            if (bme_ok) {
                // A value of 0 tells the UI "no data yet" and it shows "Warming".
                uint16_t eco2_raw = 0;
                uint16_t tvoc_raw = 0;

                if (ccs_ok && ccs_data.eco2 > 0) {
                    eco2_raw = ccs_data.eco2;
                }
                if ((ens_ok || ens_warmup) && ens_data.tvoc > 0 && ens_data.tvoc <= 10000) {
                    tvoc_raw = ens_data.tvoc;
                }

                temp_history[history_index] = bme_data.temperature;
                humi_history[history_index] = bme_data.humidity;
                eco2_history[history_index] = eco2_raw;
                tvoc_history[history_index] = tvoc_raw;
                history_index = (history_index + 1) % AVG_SAMPLES;
                if (history_count < AVG_SAMPLES) {
                    history_count++;
                }

                // eCO2/TVOC slots holding 0 ("no data yet") are left out of
                // their averages, so the first real readings after warm-up
                // aren't pulled down towards 0.
                float temp_avg = 0;
                float humi_avg = 0;
                uint32_t eco2_sum = 0;
                uint32_t tvoc_sum = 0;
                uint8_t eco2_n = 0;
                uint8_t tvoc_n = 0;
                for (uint8_t i = 0; i < history_count; i++) {
                    temp_avg += temp_history[i];
                    humi_avg += humi_history[i];
                    if (eco2_history[i] > 0) {
                        eco2_sum += eco2_history[i];
                        eco2_n++;
                    }
                    if (tvoc_history[i] > 0) {
                        tvoc_sum += tvoc_history[i];
                        tvoc_n++;
                    }
                }
                temp_avg /= history_count;
                humi_avg /= history_count;
                uint16_t eco2_avg = eco2_n ? eco2_sum / eco2_n : 0;
                uint16_t tvoc_avg = tvoc_n ? tvoc_sum / tvoc_n : 0;

                ui_air_quality_update(temp_avg, humi_avg, eco2_avg, tvoc_avg);

                ESP_LOGI(TAG, "Avg over %u samples: %.1f C, %.1f %% | eCO2 %u ppm (CCS811) | TVOC %u ppb (ENS160)",
                         history_count, temp_avg, humi_avg, eco2_avg, tvoc_avg);
                if (eco2_raw == 0) {
                    ESP_LOGW(TAG, "eCO2 warming up (CCS811: %u ppm)", ccs_data.eco2);
                }
                if (tvoc_raw == 0) {
                    ESP_LOGW(TAG, "TVOC warming up (ENS160: %u ppb)", ens_data.tvoc);
                }
            }
        }
        loop_count++;

        vTaskDelay(pdMS_TO_TICKS(LOOP_PERIOD_MS));
    }
}

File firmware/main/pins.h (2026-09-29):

/*
 * pins.h - every GPIO this firmware uses, in one place.
 *
 * Board: ESP32-32E (ESP32-WROOM-32) with a 3.2" 240x320 ST7789P3 IPS display
 * and an XPT2046 resistive touch controller (sold as "E32R32P").
 *
 * The I2C pins are used directly by this firmware.
 * The display and touch pins are consumed by the lvgl_esp32_drivers component,
 * which reads them from Kconfig (see sdkconfig.defaults). They are repeated here
 * so the whole pin map is in one file, and the static asserts below fail the
 * build if the two ever disagree.
 */
#pragma once

#include "sdkconfig.h"

/* ---- I2C sensor bus: BME680 (0x77), CCS811 (0x5A), ENS160 (0x53) ---- */
#define PIN_I2C_SDA          32
#define PIN_I2C_SCL          25
#define I2C_BUS_FREQ_HZ      100000

/* ---- Display: ST7789P3 on SPI2 (HSPI) ---- */
#define PIN_SPI_MOSI         13
#define PIN_SPI_MISO         12   /* only the touch controller talks back */
#define PIN_SPI_CLK          14
#define PIN_LCD_CS           15
#define PIN_LCD_DC            2
#define PIN_LCD_BACKLIGHT    27   /* active high */
/* The panel's reset line is wired to the ESP32 EN pin, so there is no reset
 * GPIO. The driver sends a software reset (command 0x01) instead. */

/* ---- Touch: XPT2046, shares the SPI2 bus with the display ---- */
#define PIN_TOUCH_CS         33
#define PIN_TOUCH_IRQ        36   /* input-only pin, low while touched */

/* ---- Keep this file and the Kconfig values in sync ---- */
_Static_assert(PIN_SPI_MOSI == CONFIG_LV_DISP_SPI_MOSI, "display MOSI differs from sdkconfig");
_Static_assert(PIN_SPI_MISO == CONFIG_LV_DISP_SPI_MISO, "display MISO differs from sdkconfig");
_Static_assert(PIN_SPI_CLK == CONFIG_LV_DISP_SPI_CLK, "display CLK differs from sdkconfig");
_Static_assert(PIN_LCD_CS == CONFIG_LV_DISP_SPI_CS, "display CS differs from sdkconfig");
_Static_assert(PIN_LCD_DC == CONFIG_LV_DISP_PIN_DC, "display DC differs from sdkconfig");
_Static_assert(PIN_LCD_BACKLIGHT == CONFIG_LV_DISP_PIN_BCKL, "backlight pin differs from sdkconfig");
_Static_assert(PIN_SPI_MOSI == CONFIG_LV_TOUCH_SPI_MOSI, "touch MOSI differs from sdkconfig");
_Static_assert(PIN_SPI_MISO == CONFIG_LV_TOUCH_SPI_MISO, "touch MISO differs from sdkconfig");
_Static_assert(PIN_SPI_CLK == CONFIG_LV_TOUCH_SPI_CLK, "touch CLK differs from sdkconfig");
_Static_assert(PIN_TOUCH_CS == CONFIG_LV_TOUCH_SPI_CS, "touch CS differs from sdkconfig");
_Static_assert(PIN_TOUCH_IRQ == CONFIG_LV_TOUCH_PIN_IRQ, "touch IRQ differs from sdkconfig");

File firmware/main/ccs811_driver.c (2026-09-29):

/*
 * ccs811_driver.c - minimal register-level driver for the ams/ScioSense CCS811.
 *
 * The CCS811 provides the eCO2 value shown on the display. Its nWAKE pin must
 * be held low (tied to GND) for it to answer on I2C.
 */
#include "ccs811_driver.h"
#include "esp_log.h"
#include "freertos/FreeRTOS.h"
#include "freertos/task.h"

#include "i2c_bus.h"

// 0x5A = ADDR pin low. Modules with ADDR pulled high answer at 0x5B.
#define CCS811_I2C_ADDR         0x5A

// Register map

#define CCS811_STATUS           0x00
#define CCS811_MEAS_MODE        0x01
#define CCS811_ALG_RESULT_DATA  0x02
#define CCS811_ENV_DATA         0x05
#define CCS811_HW_ID            0x20
#define CCS811_HW_VERSION       0x21
#define CCS811_FW_APP_VERSION   0x24
#define CCS811_ERROR_ID         0xE0
#define CCS811_APP_START        0xF4
#define CCS811_SW_RESET         0xFF

// Drive modes
#define CCS811_DRIVE_MODE_IDLE  0x00
#define CCS811_DRIVE_MODE_1SEC  0x10
#define CCS811_DRIVE_MODE_10SEC 0x20
#define CCS811_DRIVE_MODE_60SEC 0x30

static const char *TAG = "CCS811";

static int8_t ccs811_i2c_read(uint8_t reg_addr, uint8_t *data, uint16_t len)
{
    return (i2c_bus_read_reg(CCS811_I2C_ADDR, reg_addr, data, len) == ESP_OK) ? 0 : -1;
}

static int8_t ccs811_i2c_write(uint8_t reg_addr, uint8_t *data, uint16_t len)
{
    return (i2c_bus_write_reg(CCS811_I2C_ADDR, reg_addr, data, len) == ESP_OK) ? 0 : -1;
}

// Command without payload (e.g. APP_START)
static int8_t ccs811_i2c_write_cmd(uint8_t reg_addr)
{
    return ccs811_i2c_write(reg_addr, NULL, 0);
}

int8_t ccs811_init_sensor(void)
{
    uint8_t hw_id;
    uint8_t status;

    // Read Hardware ID
    if (ccs811_i2c_read(CCS811_HW_ID, &hw_id, 1) != 0) {
        ESP_LOGE(TAG, "Failed to read HW ID");
        return -1;
    }

    if (hw_id != 0x81) {
        ESP_LOGE(TAG, "Invalid HW ID: 0x%02X (expected 0x81)", hw_id);
        return -1;
    }

    ESP_LOGI(TAG, "CCS811 HW ID verified: 0x%02X", hw_id);

    // Read status register
    if (ccs811_i2c_read(CCS811_STATUS, &status, 1) != 0) {
        ESP_LOGE(TAG, "Failed to read status");
        return -1;
    }

    ESP_LOGI(TAG, "Initial status: 0x%02X", status);

    // Check if app is valid (bit 4)
    if ((status & 0x10) == 0) {
        ESP_LOGE(TAG, "App not valid!");
        return -1;
    }

    // Check if in boot mode (bit 7 = 0 means boot mode)
    if ((status & 0x80) == 0) {
        ESP_LOGI(TAG, "Sensor in boot mode, starting app...");

        // Start application
        if (ccs811_i2c_write_cmd(CCS811_APP_START) != 0) {
            ESP_LOGE(TAG, "Failed to start app");
            return -1;
        }

        vTaskDelay(pdMS_TO_TICKS(100));

        // Re-read status
        if (ccs811_i2c_read(CCS811_STATUS, &status, 1) != 0) {
            ESP_LOGE(TAG, "Failed to read status after app start");
            return -1;
        }

        ESP_LOGI(TAG, "Status after app start: 0x%02X", status);
    }

    // Check for errors (bit 0)
    if (status & 0x01) {
        uint8_t error;
        if (ccs811_i2c_read(CCS811_ERROR_ID, &error, 1) == 0) {
            ESP_LOGE(TAG, "Sensor error: 0x%02X", error);
        }
        return -1;
    }

    // Set drive mode to 1 second measurements
    uint8_t meas_mode = CCS811_DRIVE_MODE_1SEC;
    if (ccs811_i2c_write(CCS811_MEAS_MODE, &meas_mode, 1) != 0) {
        ESP_LOGE(TAG, "Failed to set measurement mode");
        return -1;
    }

    // Wait for sensor to start measurements (first reading takes ~1 second)
    vTaskDelay(pdMS_TO_TICKS(1000));

    // Verify sensor is measuring
    if (ccs811_i2c_read(CCS811_STATUS, &status, 1) == 0) {
        ESP_LOGI(TAG, "Status after mode set: 0x%02X", status);
        if (status & 0x01) {
            uint8_t error;
            if (ccs811_i2c_read(CCS811_ERROR_ID, &error, 1) == 0) {
                ESP_LOGW(TAG, "Sensor has error after init: 0x%02X", error);
            }
        }
    }

    ESP_LOGI(TAG, "CCS811 initialized successfully (1-second mode)");
    ESP_LOGW(TAG, "Sensor warming up - wait 20 minutes for accurate readings");

    return 0;
}

int8_t ccs811_set_environment(float temp_c, float humi_rh)
{
    // Temperature: (temp + 25) * 512
    // Humidity: humidity * 512
    uint16_t temp_conv = (uint16_t)((temp_c + 25.0f) * 512.0f);
    uint16_t humi_conv = (uint16_t)(humi_rh * 512.0f);

    uint8_t env_data[4] = {
        (uint8_t)((humi_conv >> 8) & 0xFF),  // Humidity MSB
        (uint8_t)(humi_conv & 0xFF),         // Humidity LSB
        (uint8_t)((temp_conv >> 8) & 0xFF),  // Temperature MSB
        (uint8_t)(temp_conv & 0xFF)          // Temperature LSB
    };

    // Retry a few times in case of I2C collision
    for (int retry = 0; retry < 3; retry++) {
        if (ccs811_i2c_write(CCS811_ENV_DATA, env_data, 4) == 0) {
            return 0;  // Success
        }
        vTaskDelay(pdMS_TO_TICKS(10));  // Small delay before retry
    }

    // Only log error if all retries failed (suppress occasional glitches)
    ESP_LOGD(TAG, "Failed to set environmental data after retries (not critical)");
    return -1;
}

bool ccs811_data_available(void)
{
    uint8_t status;

    if (ccs811_i2c_read(CCS811_STATUS, &status, 1) != 0) {
        return false;
    }

    // Bit 3: DATA_READY
    return (status & 0x08) != 0;
}
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

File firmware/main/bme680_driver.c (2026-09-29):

/*
 * bme680_driver.c - thin wrapper around the Bosch BME68x Sensor API.
 *
 * The BME680 provides temperature and humidity for the display, and the same
 * values are fed to the CCS811 and ENS160 for their compensation.
 */
#include "bme680_driver.h"
#include "bme68x.h"
#include "esp_log.h"
#include "esp_rom_sys.h"

#include "i2c_bus.h"

// 0x77 = SDO pin high. If your module answers at 0x76 instead, use BME68X_I2C_ADDR_LOW.
#define BME_ADDR            BME68X_I2C_ADDR_HIGH

static const char *TAG = "BME680";
static struct bme68x_dev g_bme;
static struct bme68x_conf g_conf;
static struct bme68x_heatr_conf g_heatr_conf;
static uint32_t g_del_period;

// Bosch API callbacks: plain register read/write on the shared I2C bus
static int8_t user_i2c_read(uint8_t reg_addr, uint8_t *reg_data, uint32_t len, void *intf_ptr)
{
    (void)intf_ptr;
    return (i2c_bus_read_reg(BME_ADDR, reg_addr, reg_data, len) == ESP_OK) ? BME68X_OK : BME68X_E_COM_FAIL;
}

static int8_t user_i2c_write(uint8_t reg_addr, const uint8_t *reg_data, uint32_t len, void *intf_ptr)
{
    (void)intf_ptr;
    return (i2c_bus_write_reg(BME_ADDR, reg_addr, reg_data, len) == ESP_OK) ? BME68X_OK : BME68X_E_COM_FAIL;
}

// User delay function (microseconds)
static void user_delay_us(uint32_t period, void *intf_ptr)
{
    (void)intf_ptr;
    esp_rom_delay_us(period);
}

int8_t bme680_init_sensor(void)
{
    // Setup BME68x device structure
    g_bme.intf = BME68X_I2C_INTF;
    g_bme.intf_ptr = NULL;
    g_bme.read = user_i2c_read;
    g_bme.write = user_i2c_write;
    g_bme.delay_us = user_delay_us;
    g_bme.amb_temp = 25;  // Ambient temperature for calculations

    // Initialize the sensor
    int8_t rslt = bme68x_init(&g_bme);
    if (rslt != BME68X_OK) {
        ESP_LOGE(TAG, "BME680 init failed! Error code: %d", rslt);
        return -1;
    }

    ESP_LOGI(TAG, "BME680 initialized successfully");

    // Configure sensor settings
    g_conf.os_hum = BME68X_OS_2X;      // 2x oversampling for humidity
    g_conf.os_pres = BME68X_OS_4X;     // 4x oversampling for pressure
    g_conf.os_temp = BME68X_OS_8X;     // 8x oversampling for temperature
    g_conf.filter = BME68X_FILTER_SIZE_3;
    g_conf.odr = BME68X_ODR_NONE;

    rslt = bme68x_set_conf(&g_conf, &g_bme);
    if (rslt != BME68X_OK) {
        ESP_LOGE(TAG, "Failed to set config! Error code: %d", rslt);
        return -1;
    }

    // The gas-plate heater is switched off. The BME680 gas reading is not shown
    // on the display (the CCS811 and ENS160 cover air quality), and the heater
    // warms the sensor and skews the temperature and humidity readings. Set
    // .enable to BME68X_ENABLE to use gas resistance (e.g. for your own IAQ index).
    g_heatr_conf.enable = BME68X_DISABLE;
    g_heatr_conf.heatr_temp = 320;     // °C (only used when the heater is enabled)
    g_heatr_conf.heatr_dur = 150;      // ms (only used when the heater is enabled)

    rslt = bme68x_set_heatr_conf(BME68X_FORCED_MODE, &g_heatr_conf, &g_bme);
    if (rslt != BME68X_OK) {
        ESP_LOGE(TAG, "Failed to set heater config! Error code: %d", rslt);
        return -1;
    }

    // Calculate measurement delay
    g_del_period = bme68x_get_meas_dur(BME68X_FORCED_MODE, &g_conf, &g_bme);
    if (g_heatr_conf.enable == BME68X_ENABLE) {
        g_del_period += g_heatr_conf.heatr_dur * 1000;
    }

    ESP_LOGI(TAG, "BME680 configuration complete. Measurement delay: %lu us", g_del_period);

    return 0;
}

int8_t bme680_trigger_measurement(void)
{
    int8_t rslt = bme68x_set_op_mode(BME68X_FORCED_MODE, &g_bme);
    if (rslt != BME68X_OK) {
        ESP_LOGE(TAG, "Failed to set forced mode! Error code: %d", rslt);
        return -1;
    }

    return 0;
}

int8_t bme680_read_data(bme680_data_t *data)
{
    if (data == NULL) {
        return -1;
    }

    // Wait for measurement to complete
    user_delay_us(g_del_period, NULL);

    struct bme68x_data sensor_data;
    uint8_t n_fields;

    int8_t rslt = bme68x_get_data(BME68X_FORCED_MODE, &sensor_data, &n_fields, &g_bme);

    if (rslt != BME68X_OK) {
        ESP_LOGE(TAG, "Failed to get data! Error code: %d", rslt);
        data->valid = false;
        return -1;
    }

    if (n_fields == 0) {
        ESP_LOGW(TAG, "No new data available");
        data->valid = false;
        return -1;
    }

    // Fill output structure
    data->temperature = sensor_data.temperature;
    data->humidity = sensor_data.humidity;
    data->pressure = sensor_data.pressure / 100.0f;  // Convert Pa to hPa
    data->gas_resistance = sensor_data.gas_resistance / 1000.0f;  // Convert Ω to kΩ
    data->valid = true;

    return 0;
}

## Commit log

2026-09-29 Initial commit: ESP32 air-quality monitor (firmware, enclosure, docs)
    [assembly.scad, case_base.scad, case_base.stl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]
2026-09-29 docs: clarify three sensor modules vs four values (ENS160+AHT21 board, exact parts bought)

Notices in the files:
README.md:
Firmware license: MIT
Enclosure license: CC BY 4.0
